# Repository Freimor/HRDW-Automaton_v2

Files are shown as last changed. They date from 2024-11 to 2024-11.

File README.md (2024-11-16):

## HRDW-Automaton v2
Automaton v2 is a version of [HID Key](https://github.com/Freimor/HRDW-HIDKey) tuned for staff of the ANO "School 21". Main reason for redesign is changing a microcontroller to RP2040. Additional feature - you can choose type of USB connector (Male or Female) before soldering.
### Notes
- Side buttons is cool with additional plate
- Ability to choose USB type - ok, but not usable footprint must be covered by 3d printed case or elecrically isolated from circuit with 0 resistors.
- Case with glued window - NOT GOOD. Unreasonable assembly step.
- DON'T MESSED UP WITH CORE VOLTAGE!!! (1v1)

The project is completed in Q2 2023.




## Parameters for PCB order
4 layer board

0.8mm thickness

0.3mm min hole size

BOM list in HTML file named BOM

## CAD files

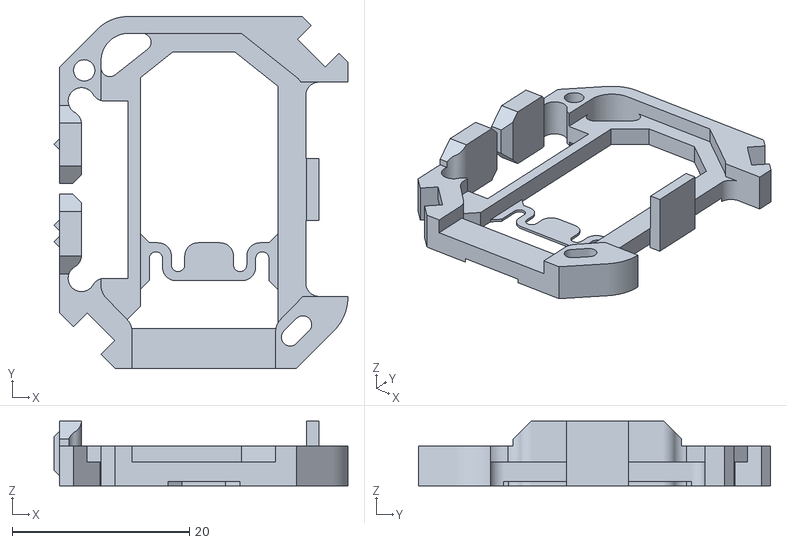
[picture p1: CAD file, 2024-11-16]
3d models/Automaton_v2_CASE_back.stl
33.2 x 39.7 x 7.28

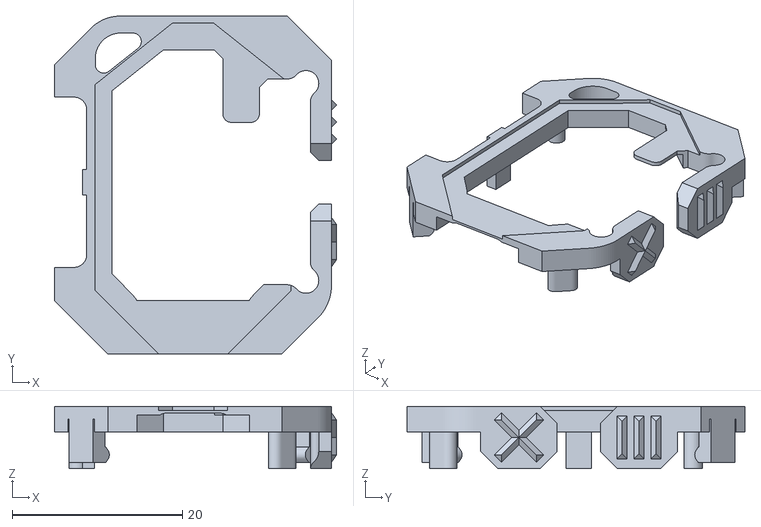
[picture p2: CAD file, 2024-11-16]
3d models/Automaton_v2_CASE_front.stl
33.2 x 39.7 x 7.30

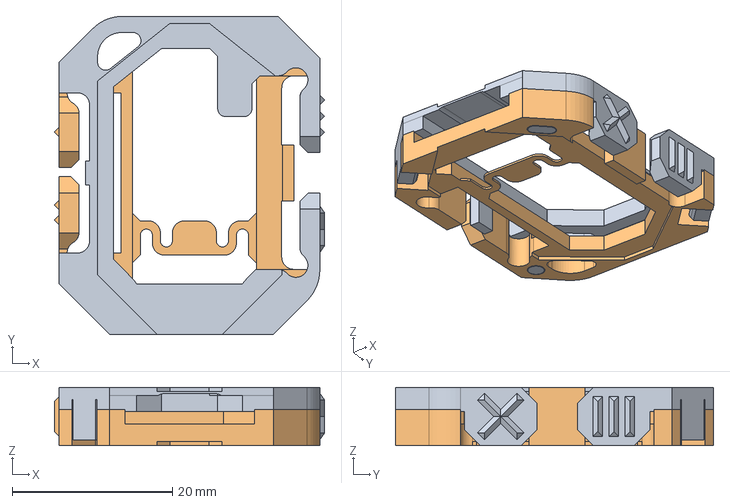
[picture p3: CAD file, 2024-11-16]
3d models/Automaton_v2_CASE.step
33.8 x 39.7 x 7.30 mm

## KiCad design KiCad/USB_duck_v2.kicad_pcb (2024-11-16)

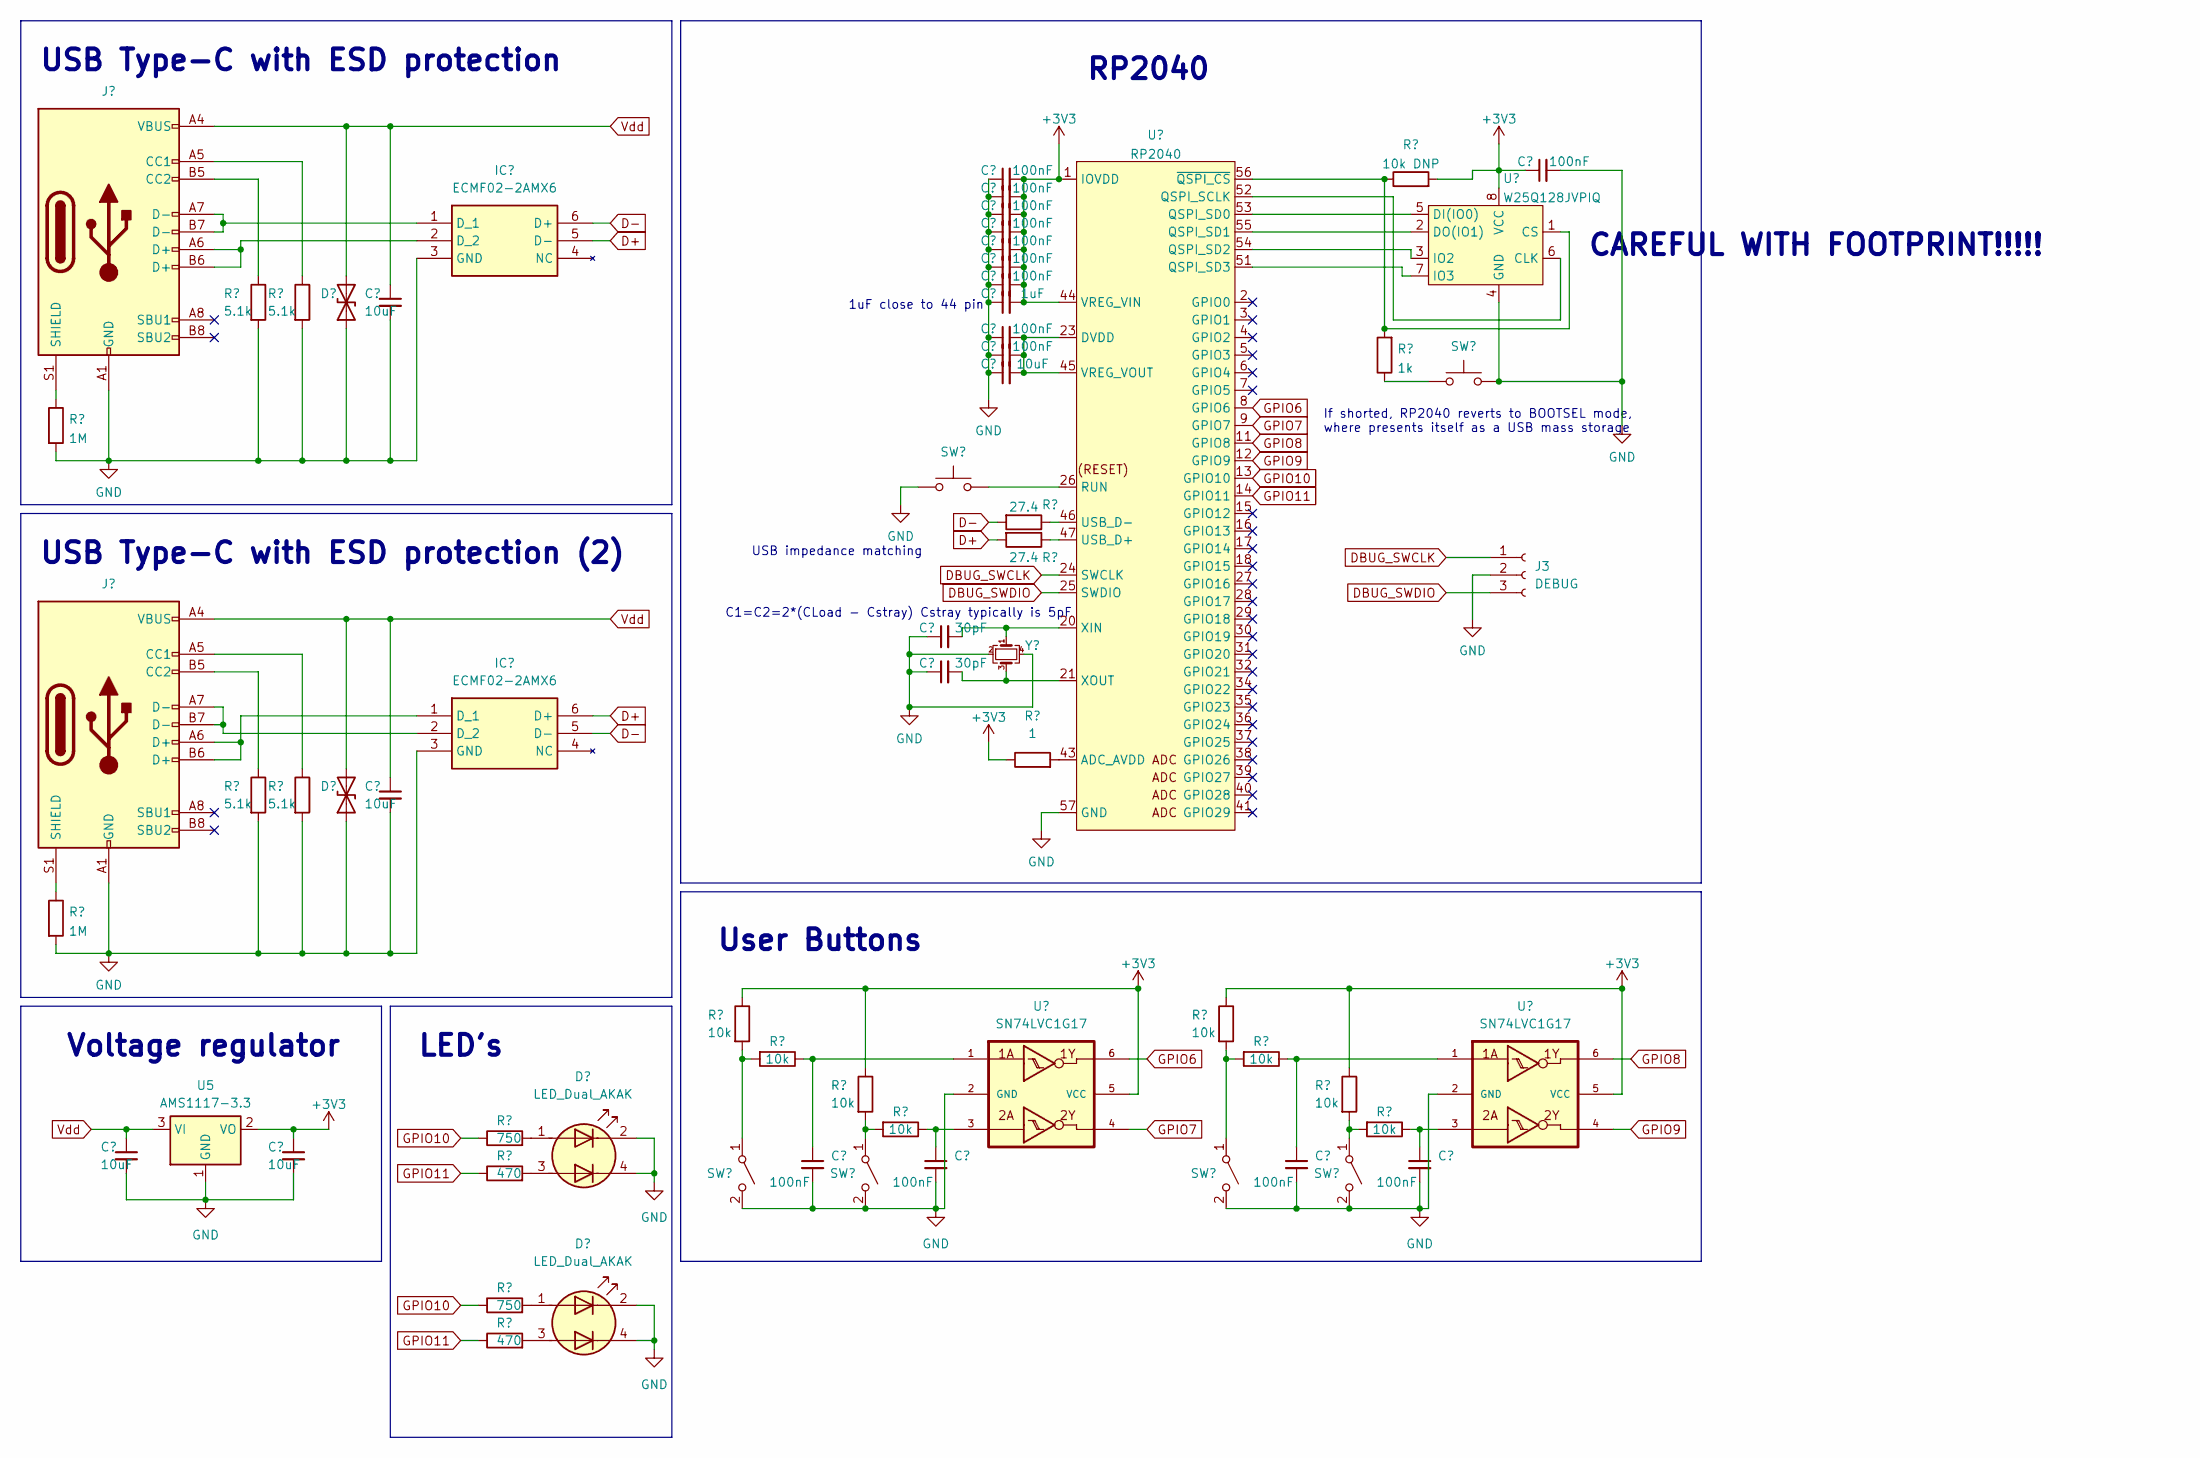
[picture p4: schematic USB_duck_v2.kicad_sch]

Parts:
BOOTSEL1: BOOTSEL; SW_SMD_XKB_(TS-1809SM-C)
C1, C2, C3, C4, C5, C6, C7, C8, C11, C12, C19, C20, C21, C22: 100nF; C_0402_1005Metric
C9, C13, C16, C17, C18: 10uF; C_0603_1608Metric
C10: 1uF; C_0603_1608Metric
C14, C15: 30pF; C_0402_1005Metric
D1, D2: D_TVS; ESD_PGB1010603MR
D3, D4: LED_Dual_AKAK; LED_RG_KPB-3025
IC1, IC2: ECMF02-2AMX6; ESD_ECMF02-2AMX6; Manufacturer_Part_Number ECMF02-2AMX6; Mouser Part Number 511-ECMF02-2AMX6
J1: USB_C_Receptacle_USB2.0; XKB_TYPE-C-U261-241N-4BS60
J2: USB_C_Receptacle_USB2.0; GCT_TYPE-C-USB4505-03-0-A
J3: DEBUG; PinHeader_1x03_P1.00mm_Vertical
R1: 10k DNP; R_0402_1005Metric
R2, R3, R9, R10: 5.1k; R_0402_1005Metric
R4: 1k; R_0402_1005Metric
R5, R11: 1M; R_0402_1005Metric
R6, R7: 27.4; R_0402_1005Metric
R8: 1; R_0402_1005Metric
R12, R13, R14, R15, R16, R17, R18, R19: 10k; R_0402_1005Metric
R20, R22: 750; R_0402_1005Metric
R21, R23: 470; R_0402_1005Metric
SW1: SW_Push; SW_SMD_XKB_(TS-1809SM-C)
SW2, SW3, SW4, SW5: SW_SPST; SW_SMD_KLS7-TS5401
U1: RP2040; MK_RP2040
U2: W25Q128JVPIQ; FLASH_W25Q128JVPIQ
U3, U4: SN74LVC1G17; SOT-23-6
U5: AMS1117-3.3; SOT-89-3
Y1: Crystal_GND24_Small; Crystal_SMD_3225-4Pin_3.2x2.5mm

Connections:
+3V3: C1.1, C2.2, C3.2, C4.2, C5.2, C6.2, C7.2, C8.2, C10.2, C18.1, R1.2, R8.1, R12.1, R13.1, R16.1, R17.1, U1.1 (IOVDD), U1.10 (IOVDD), U1.22 (IOVDD), U1.33 (IOVDD), U1.42 (IOVDD), U1.44 (VREG_VIN), U1.48 (USB_VDD), U1.49 (IOVDD), U2.8 (VCC), U3.5 (VCC), U4.5 (VCC), U5.2 (VO)
D+: IC1.5 (D-), IC2.6 (D+), R7.2
D-: IC1.6 (D+), IC2.5 (D-), R6.2
DBUG_SWCLK: J3.1, U1.24 (SWCLK)
DBUG_SWDIO: J3.3, U1.25 (SWDIO)
GND: BOOTSEL1.2, C1.2, C2.1, C3.1, C4.1, C5.1, C6.1, C7.1, C8.1, C9.2, C10.1, C11.1, C12.1, C13.1, C14.1, C15.1, C16.2, C17.2, C18.2, C19.2, C20.2, C21.2, C22.2, D1.1 (A1), D2.1 (A1), D3.2 (K1), D3.4 (K2), D4.2 (K1), D4.4 (K2), IC1.3 (GND), IC2.3 (GND), J1.A1 (GND), J1.A12 (GND), J1.B1 (GND), J1.B12 (GND), J2.A1 (GND), J2.A12 (GND), J2.B1 (GND), J2.B12 (GND), J3.2, R2.2, R3.2, R5.2, R9.2, R10.2, R11.2, SW1.1, SW2.2 (B), SW3.2 (B), SW4.2 (B), SW5.2 (B), U1.19 (TESTEN), U1.57 (GND), U2.4 (GND), U3.2 (GND), U4.2 (GND), U5.1 (GND), Y1.2, Y1.4; also elsewhere on the board
GPIO6: U1.8 (GPIO6), U3.6
GPIO7: U1.9 (GPIO7), U3.4
GPIO8: U1.11 (GPIO8), U4.6
GPIO9: U1.12 (GPIO9), U4.4
GPIO10: R20.1, R22.1, U1.13 (GPIO10)
GPIO11: R21.1, R23.1, U1.14 (GPIO11)
unnamed: BOOTSEL1.1, R4.1
unnamed: C19.1, R14.1, U3.1
unnamed: C20.1, R18.1, U3.3
unnamed: C21.1, R15.1, U4.1
unnamed: C22.1, R19.1, U4.3
unnamed: D3.1 (A1), R20.2
unnamed: D3.3 (A2), R21.2
unnamed: D4.1 (A1), R22.2
unnamed: D4.3 (A2), R23.2
unnamed: IC1.1 (D_1), J1.A7 (D-), J1.B7 (D-)
unnamed: IC1.2 (D_2), J1.A6 (D+), J1.B6 (D+)
unnamed: IC2.1 (D_1), J2.A6 (D+), J2.B6 (D+)
unnamed: IC2.2 (D_2), J2.A7 (D-), J2.B7 (D-)
unnamed: J1.A5 (CC1), R3.1
unnamed: J1.B5 (CC2), R2.1
unnamed: J1.S1 (SHIELD), R5.1
unnamed: J2.A5 (CC1), R10.1
unnamed: J2.B5 (CC2), R9.1
unnamed 30: J2.S1 (SHIELD), R11.1; also elsewhere on the board
unnamed: R12.2, R14.2, SW2.1 (A)
unnamed: R16.2, R18.2, SW3.1 (A)
unnamed: R13.2, R15.2, SW4.1 (A)
unnamed: R17.2, R19.2, SW5.1 (A)
unnamed: R8.2, U1.43 (ADC_AVDD)
unnamed: U1.52 (QSPI_SCLK), U2.6 (CLK)
unnamed: U1.53 (QSPI_SD0), U2.5 (DI(IO0))
unnamed: U1.55 (QSPI_SD1), U2.2 (DO(IO1))
unnamed: U1.54 (QSPI_SD2), U2.3 (IO2)
unnamed: U1.51 (QSPI_SD3), U2.7 (IO3)
unnamed: SW1.2, U1.26 (RUN)
unnamed: R7.1, U1.47 (USB_D+)
unnamed: R6.1, U1.46 (USB_D-)
unnamed: C11.2, C12.2, C13.2, U1.23 (DVDD), U1.45 (VREG_VOUT), U1.50 (DVDD)
unnamed: C14.2, U1.20 (XIN), Y1.1
unnamed: C15.2, U1.21 (XOUT), Y1.3
unnamed: R1.1, R4.2, U1.56 (~QSPI_CS), U2.1 (CS)
Vdd: C9.1, C16.1, C17.1, D1.2 (A2), D2.2 (A2), J1.A4 (VBUS), J1.A9 (VBUS), J1.B4 (VBUS), J1.B9 (VBUS), J2.A4 (VBUS), J2.A9 (VBUS), J2.B4 (VBUS), J2.B9 (VBUS), U5.3 (VI)

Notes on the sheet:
USB impedance matching
USB Type-C with ESD protection (2)
USB Type-C with ESD protection
Voltage regulator
LED's
1uF close to 44 pin
If shorted, RP2040 reverts to BOOTSEL mode, where presents itself as a USB mass storage
CAREFUL WITH FOOTPRINT!!!!!
User Buttons
RP2040
C1=C2=2*(CLoad - Cstray) Cstray typically is 5pF

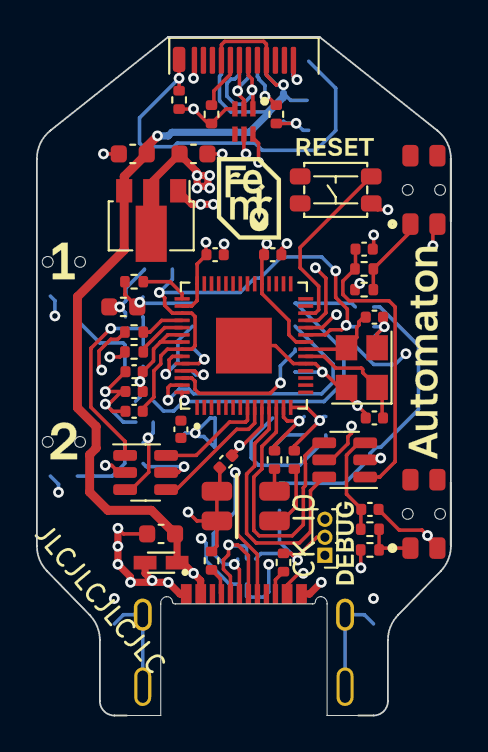
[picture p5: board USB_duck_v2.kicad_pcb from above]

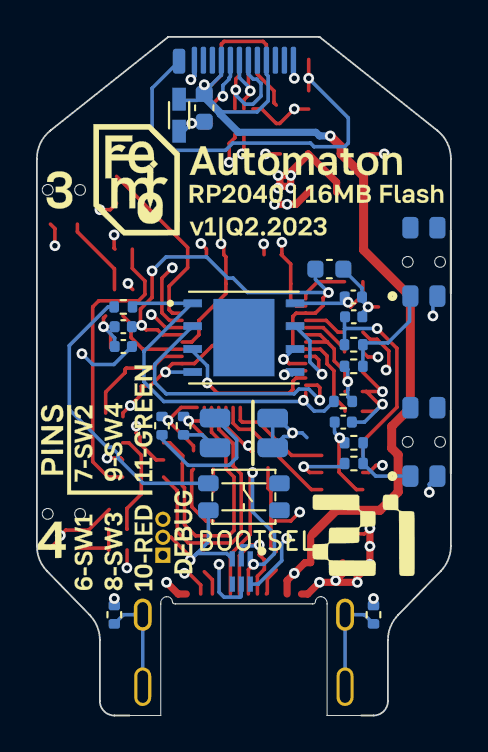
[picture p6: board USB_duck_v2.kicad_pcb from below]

Board: 4 copper layers, 23.0 x 37.7 mm, 69 parts (24 on the bottom side), 49 nets.

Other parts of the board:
R11#2: 1M; R_0402_1005Metric
Ref**: Val**; front
Ref**#2: Val**; back

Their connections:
GND: R11#2.2; also elsewhere on the board
unnamed 30: R11#2.1; also elsewhere on the board
